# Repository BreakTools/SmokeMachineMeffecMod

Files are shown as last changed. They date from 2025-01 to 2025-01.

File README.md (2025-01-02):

# WebSocket controlled smoke machine mod
Smoke machines are pretty cool. Smoke machines you can wirelessly control are even cooler, but they're also way more expensive. So instead of spending a lot of money on one I decided to spend a lot of time on modding the dirt cheap smoke machine I already own! Sharing my code and files online in case someone else has interest in doing something similar :)

https://github.com/user-attachments/assets/eef2c1eb-12a6-4686-8a88-89f622232f13

I've got a BeamZ S500 smoke machine which can be triggered by a button that's on a control unit. Luckily for us the pins on that button stick out massively on the other side, so soldering some wires to it is super easy:

smokemachine

When the button is pressed electricity flows between those two pins, which triggers the smoke machine. So all we have to do is connect those pins through a relay so we can control the smoke machine with a microcontroller. I'm hooking it up to my websocket based show effects infrastructre system called [Meffec](https://github.com/BreakTools/Meffec), but I'm sure you could come up with any number of ways of controlling a simple relay. My "tech stack" is an ESP32 C3 Super Mini board and the Arduino framework using PlatformIO for the code. For fun I'm also adding a little 128x64 OLED display, for showing things like the smoke status and if the unit is connected to WiFi and stuff. Here's the diagram for all the electronics:

moddiagram

I've also modeled and 3d printed a mount so I can screw the whole system to the bottom of the smoke machine's control unit (STL and FreeCAD file can be found in the resources folder):
model

And that's pretty much it! Total cost of the mod was about 8 euros, not a bad price for a wireless upgrade!

finalcase

Please be careful with the button wiring if you're planning on doing a mod like this yourself, as the voltage across it is roughly 70V. 

## Future work
Couple of things about this system that could be improved still:
- Whenever the relay turns off there's electrical noise which messes up the OLED display. I've "fixed" this now by just adding a delay after the relay turns off but this is clearly a hardware problem and should be fixed.
- I should buy some smaller screws that actually fit the relay.
- The 3d printed case could use some walls, but I don't have long enough screws to make that happen. I guess I need to buy more screws.
- Yeah I should go and buy some screws, like a nice good set of screws.

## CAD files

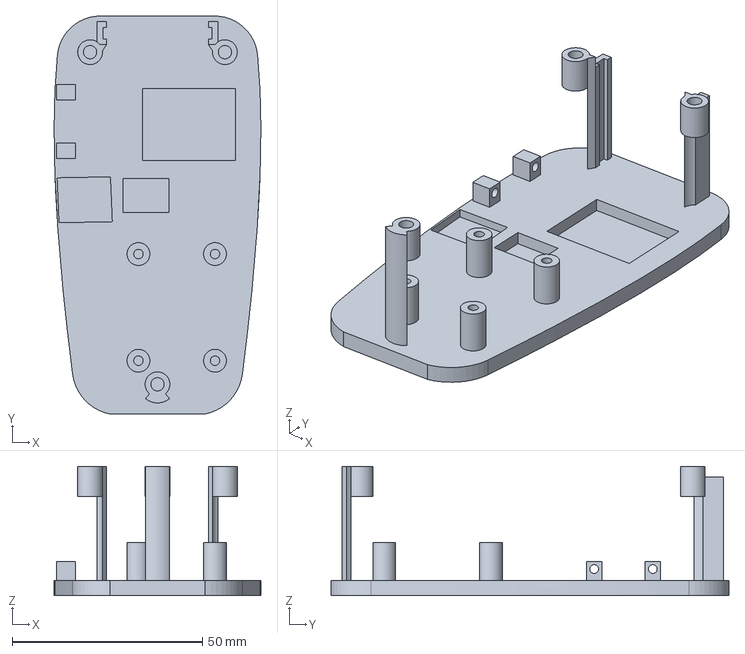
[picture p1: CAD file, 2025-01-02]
resources/SmokeModCase.FCStd
54.3 x 104.5 x 34.0 mm

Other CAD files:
resources/SmokeModCase.stl

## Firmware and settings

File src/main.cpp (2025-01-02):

#include <Arduino.h>

#include "Config.h"
#include "DataTypes.h"
#include "oled/OledHandling.h"
#include "relay/RelayHandling.h"
#include "wifi/WiFiHandling.h"
#include "meffec/MeffecHandling.h"

OledHandler oledHandler;
WifiHandler wifiHandler;
MeffecHandler meffecHandler;
RelayHandler relayHandler;

SmokeMachineData smokeMachineData;

void onSmokeTimingReceived(int smokeTimeInMillis)
{
    smokeMachineData.remainingSmokeTimeInMillis = smokeTimeInMillis;
}

void setup()
{
    relayHandler.configureRelay();
    wifiHandler.configureWiFi();
    meffecHandler.configureMeffec(onSmokeTimingReceived);
    oledHandler.configureOledDisplay();
}

void loop()
{
    smokeMachineData.isConnectedToWiFi = wifiHandler.isConnected();
    meffecHandler.processMeffecData(smokeMachineData.isConnectedToWiFi);
    smokeMachineData.isConnectedToMeffec = meffecHandler.isConnected();
    relayHandler.processSmokeMachineData(smokeMachineData);
    oledHandler.displaySmokeMachineData(smokeMachineData);
}

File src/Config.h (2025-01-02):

#ifndef CONFIG_H
#define CONFIG_H

// WiFi configuration
#define WIFI_SSID "yourssid"
#define WIFI_PASSWORD "yourpassword"

// Meffec configuration
#define MEFFEC_SERVER_URL "ws://yourmeffecurl.com"
#define MEFFEC_SERVER_TOKEN "yourmeffectoken"

// Pin configuration
#define RELAY_PIN 9
#define OLED_SCL_PIN 0
#define OLED_SDA_PIN 1

// OLED configuration
#define OLED_WIDTH 128
#define OLED_HEIGHT 64
#define OLED_I2C_ADDRESS 0x3C

// Development options
#define DISABLE_BOOT_ANIMATION 0

#endif
